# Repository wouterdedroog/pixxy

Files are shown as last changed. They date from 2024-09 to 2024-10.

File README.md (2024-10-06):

# Pixxy

Pixxy is a physical remote control for PixMob bracelets using a custom PCB. The PCB design is available in the 
[pixxy-kicad](pixxy-kicad) folder. I used KiCad 8 to design this PCB. There are currently two variations/revisions of 
this project. You're currently looking at the revision based on the RP2040 chip. 

There is also a revision based on the Raspberry Pi Pico, which is slightly cheaper and easier to assemble, but uses
micro USB instead of USB-C. This revision can be found [here](https://github.com//wouterdedroog/pixxy/tree/pico). The
MicroPython sourcecode found in the [src branch](https://github.com/wouterdedroog/pixxy/tree/src) is compatible with
both hardware versions.

## Branches
- [main](https://github.com/wouterdedroog/pixxy/tree/main) - Full project details and PCB design based on the RP2040 chip (has USB-C)
- [pico](https://github.com//wouterdedroog/pixxy/tree/pico) - PCB design based on the Raspberry Pi Pico (cheaper and easier to assemble)
- [src](https://github.com/wouterdedroog/pixxy/tree/src) - MicroPython source, compatible with both variations of Pixxy device

## Functionality
Both revisions are identical when it comes to the controls (switches and potentiometers) They both have a 4×4 button 
matrix. Eight of these buttons are used for selecting preset colours. The ninth button selects a custom colour, using 
the red/green/blue values from the potentiometers above the buttons (marked RV1, RV2 and RV3).

The Fade and Flash buttons are used to send the selected colour to the IR LED (connected to a 2N3904 transistor). The
Once / Repeat switch can be used to send the command once or multiple times.

For X2 bracelets (the ones being used at Taylor Swift concerts), it is possible to set a colour indefinitely. The On and
Off buttons are used for this. The Taylor End button sends the end/go home signal used at concerts, which causes the
bracelet to loop through a set of colours until the battery runs out. The rainbow effect does the same effect, but with
the colours of the rainbow in order.

When the Speed Set button is held down, the value of the RV3/Blue potentiometer influences the speed of the commands. 
This means the potentiometer influences how long a fade or flash command lasts, and how much time is in between these
commands if the switch is in the repeat position.

Pixxy also responds to commands over serial. You can use [this site](https://wissenhinterdenkulissen.de/armband/) which
uses WebSerial, or the Python sender scripts in the 
[pixmob-ir-reverse-engineering repo](https://github.com/danielweidman/pixmob-ir-reverse-engineering/).

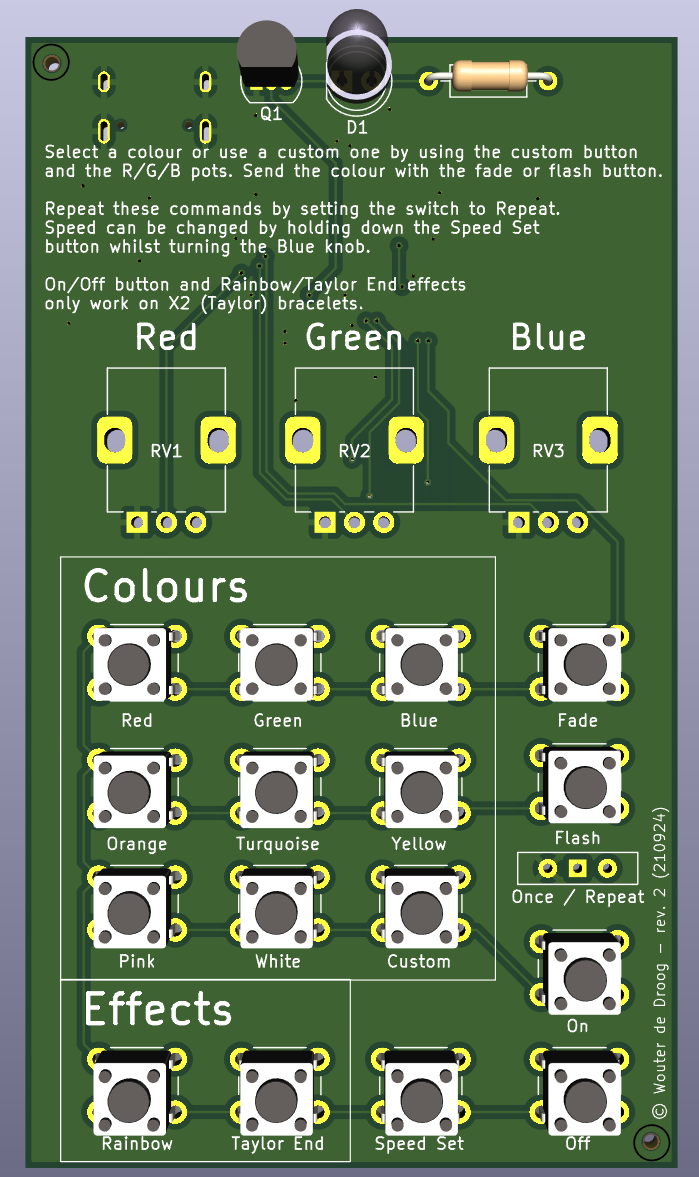
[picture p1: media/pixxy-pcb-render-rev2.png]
RP2040-based revision of the PCB


## Schematic
The PCB and schematic were made using KiCad 8. The project files are available in the
[pixxy-kicad directory](pixxy-kicad). A screenshot of the schematic can be found below:

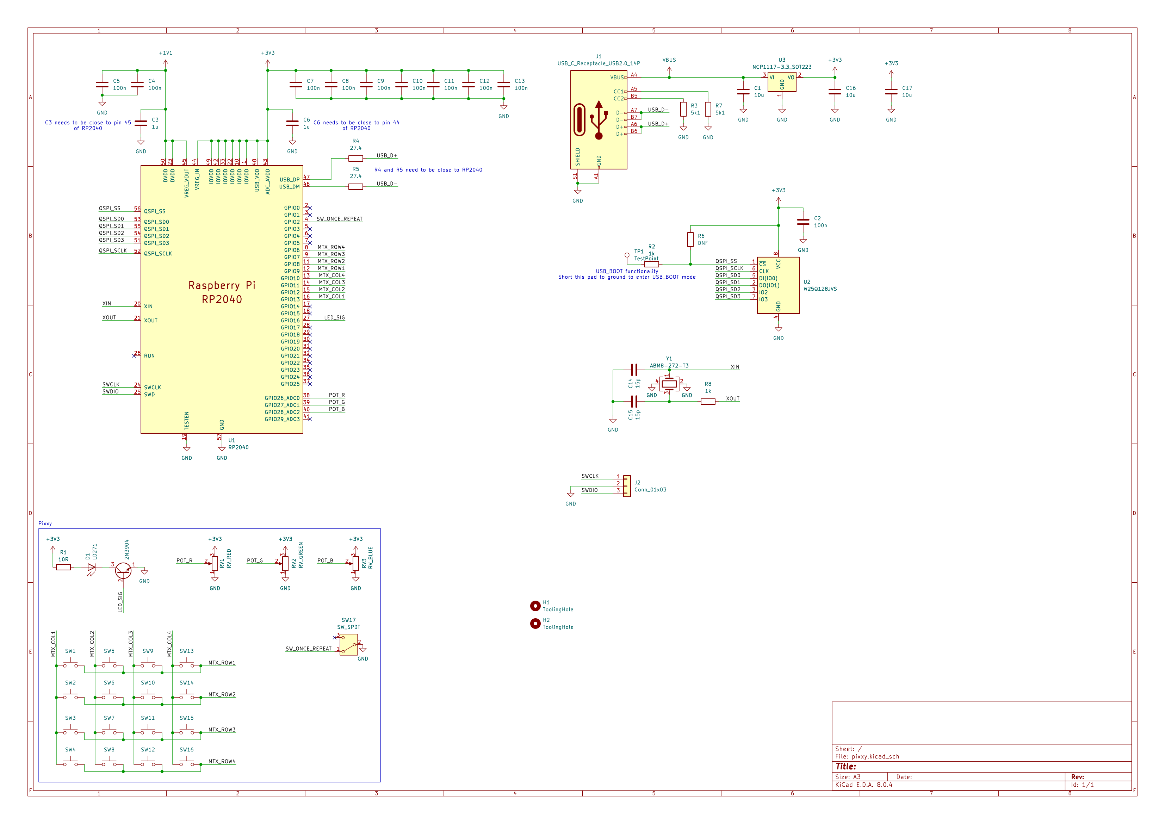
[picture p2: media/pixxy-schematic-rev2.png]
Schematic of Pixxy PCB


## Thanks
This project wouldn't have been possible without the research available in the
[pixmob-ir-reverse-engineering](https://github.com/danielweidman/pixmob-ir-reverse-engineering/) and 
[PixMob_IR](https://github.com/jamesw343/PixMob_IR/) repositories. The knowledge available in the
[PIXMOD Discord](https://discord.com/invite/UYqTjC7xp3) has also been super helpful.

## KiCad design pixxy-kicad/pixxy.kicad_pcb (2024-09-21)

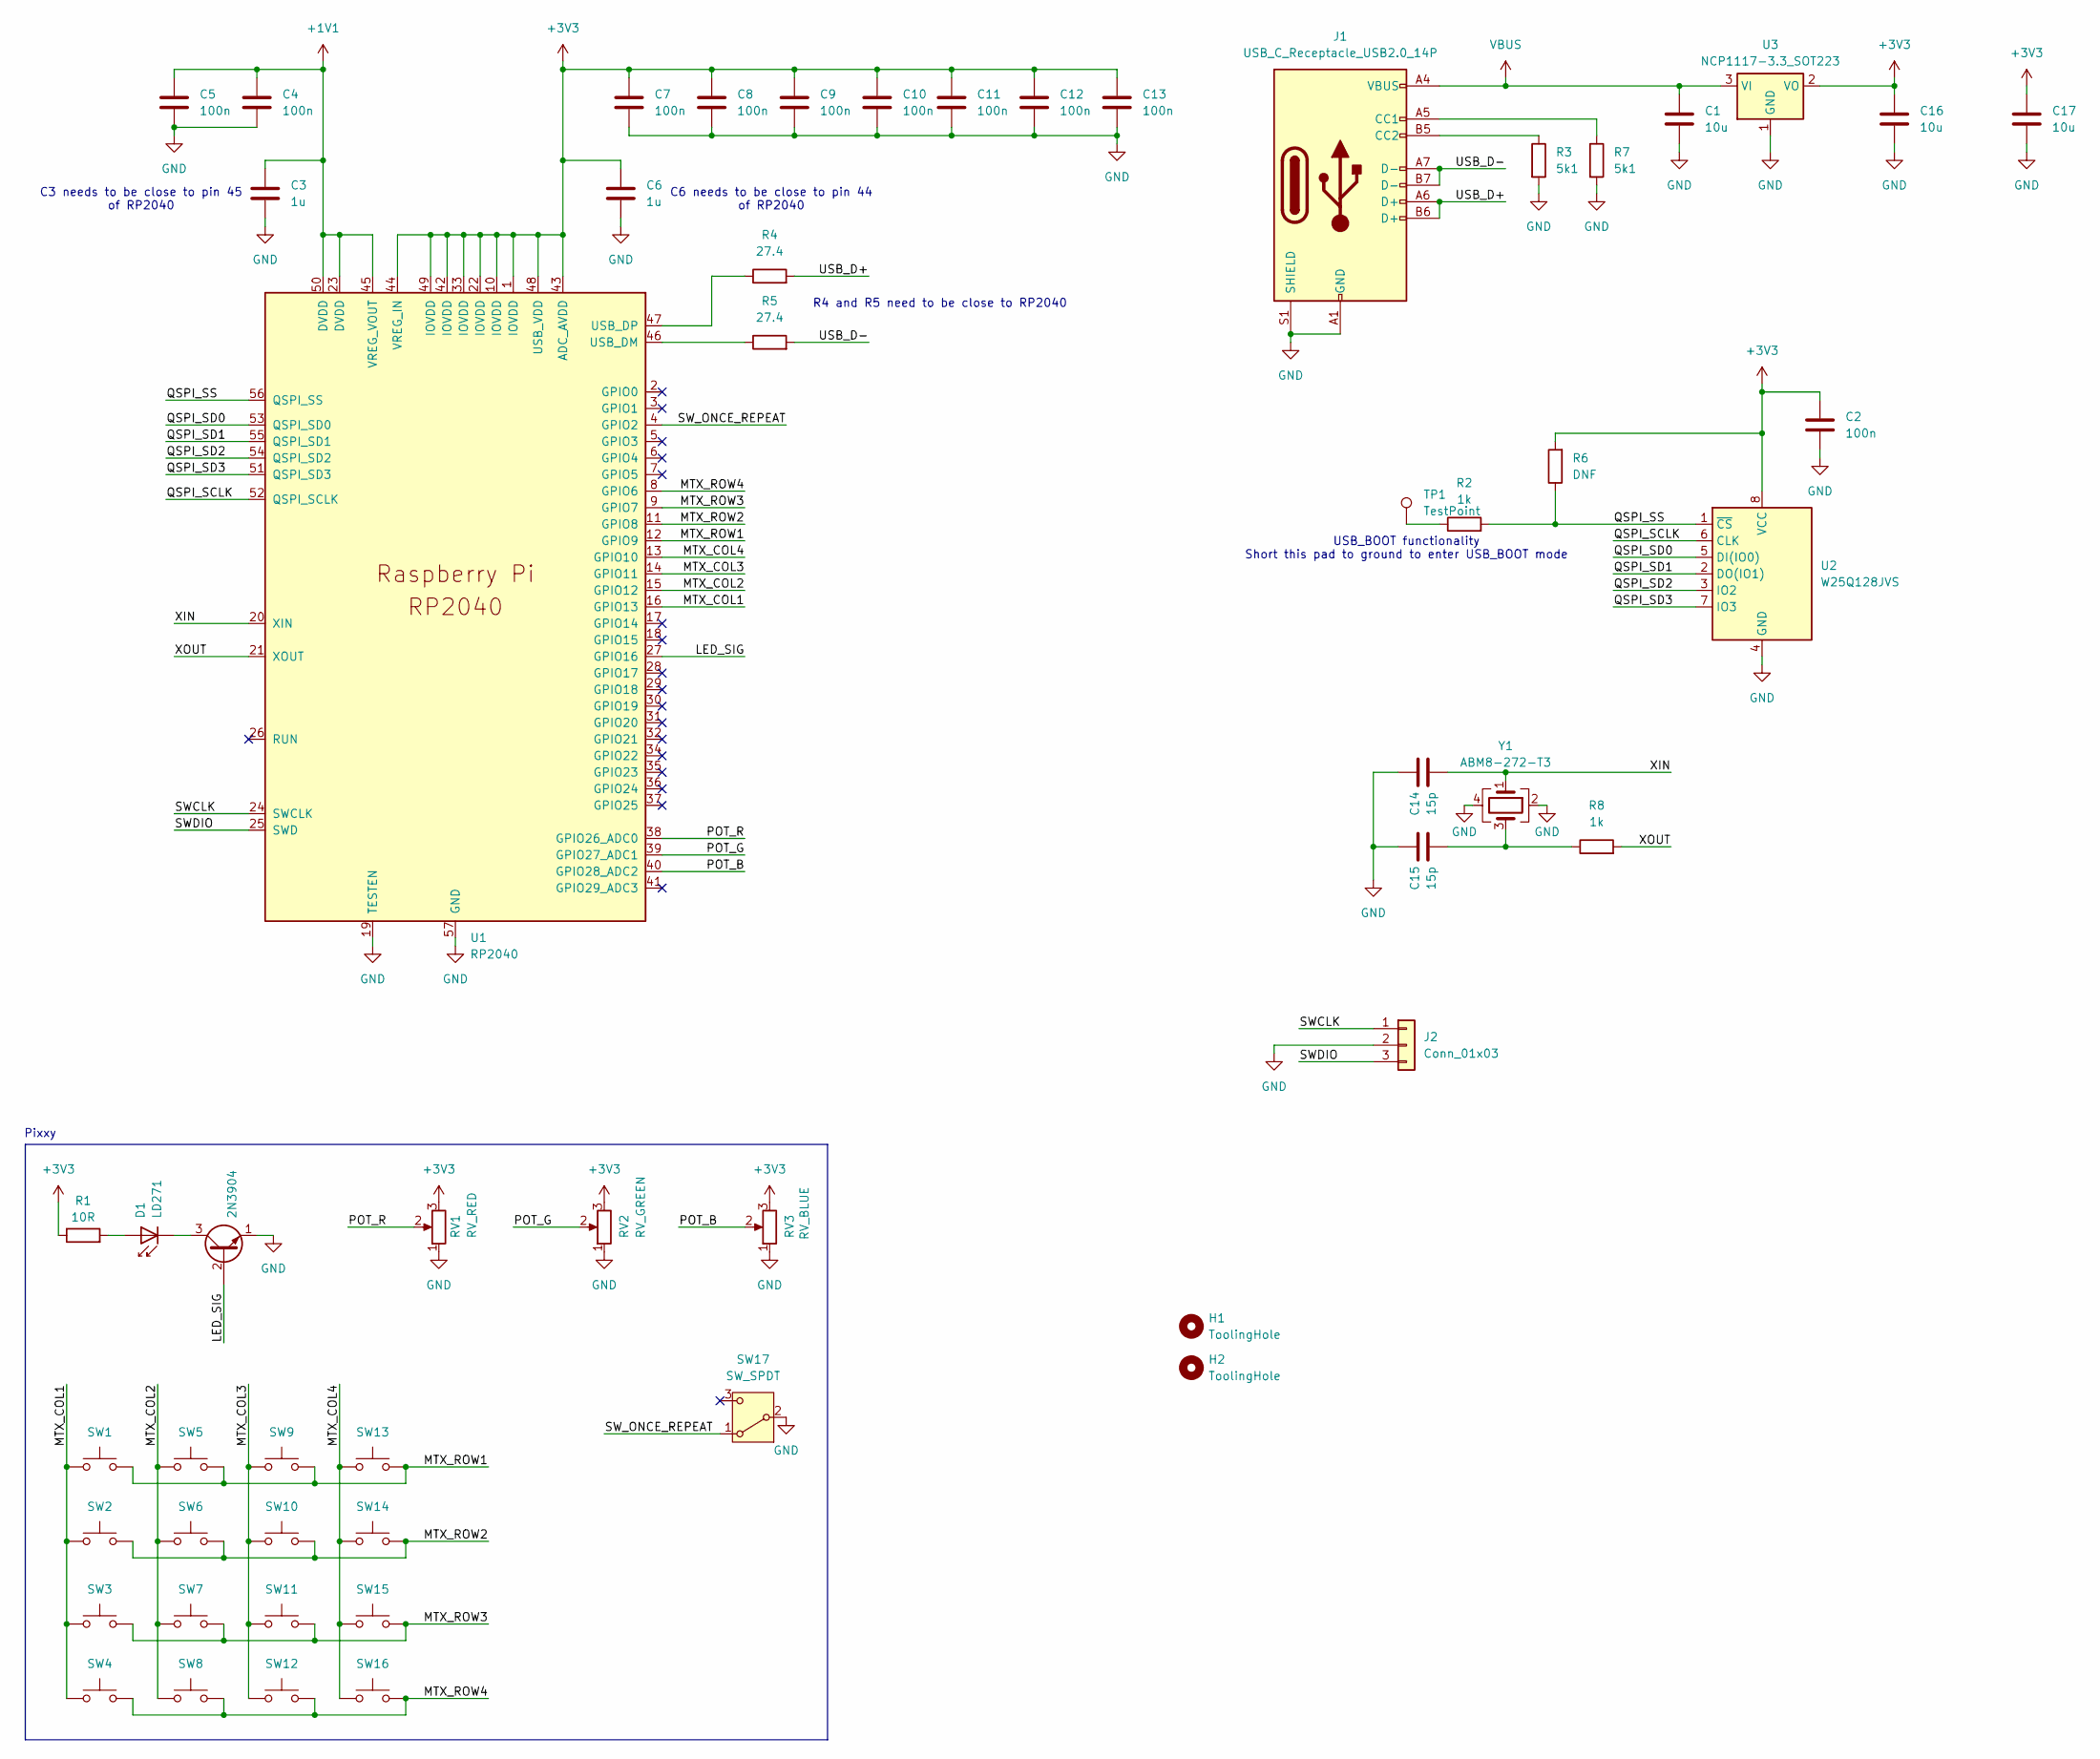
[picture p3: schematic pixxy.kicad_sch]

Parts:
C1, C16, C17: 10u; C_0805_2012Metric; LCSC C15850
C2, C4, C5, C7, C8, C9, C10, C11, C12, C13: 100n; C_0402_1005Metric; LCSC C307331
C3, C6: 1u; C_0402_1005Metric; LCSC C52923
C14, C15: 15p; C_0402_1005Metric; LCSC C1548
D1: LD271; LED_D5.0mm_IRGrey
H1, H2: ToolingHole; MountingHole_1.152mm
J1: USB_C_Receptacle_USB2.0_14P; USB_C_Receptacle_G-Switch_GT-USB-7010ASV; LCSC C2988369
J2: Conn_01x03; JST_SH_SM03B-SRSS-TB_1x03-1MP_P1.00mm_Horizontal
Q1: 2N3904; TO-92_Inline
R1: 10R; R_Axial_DIN0207_L6.3mm_D2.5mm_P10.16mm_Horizontal
R2, R8: 1k; R_0402_1005Metric; LCSC C11702
R3, R7: 5k1; R_0402_1005Metric; LCSC C25905
R4, R5: 27.4; R_0402_1005Metric; LCSC C321420
R6: DNF; R_0402_1005Metric
RV1: RV_RED; Potentiometer_Alps_RK09K_Single_Vertical
RV2: RV_GREEN; Potentiometer_Alps_RK09K_Single_Vertical
RV3: RV_BLUE; Potentiometer_Alps_RK09K_Single_Vertical
SW1, SW2, SW3, SW4, SW5, SW6, SW7, SW8, SW9, SW10, SW11, SW12, SW13, SW14, SW15, SW16: SW_PUSH_6mm
SW17: SW_SPDT; SW_Slide-03_Wuerth-WS-SLTV_10x2.5x6.4_P2.54mm
TP1: TestPoint; TestPoint_Pad_1.5x1.5mm
U1: RP2040; QFN-56-1EP_7x7mm_P0.4mm_EP3.2x3.2mm; LCSC C2040
U2: W25Q128JVS; SOIC-8_5.23x5.23mm_P1.27mm; LCSC C97521
U3: NCP1117-3.3_SOT223; SOT-223-3_TabPin2; LCSC C26537
Y1: ABM8-272-T3; Crystal_SMD_3225-4Pin_3.2x2.5mm; LCSC C20625731

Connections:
+1V1: C3.1, C4.1, C5.1, U1.23 (DVDD), U1.45 (VREG_VOUT), U1.50 (DVDD)
+3V3: C2.1, C6.1, C7.1, C8.1, C9.1, C10.1, C11.1, C12.1, C13.1, C16.1, C17.1, R1.1, R6.2, RV1.3, RV2.3, RV3.3, U1.1 (IOVDD), U1.10 (IOVDD), U1.22 (IOVDD), U1.33 (IOVDD), U1.42 (IOVDD), U1.43 (ADC_AVDD), U1.44 (VREG_IN), U1.48 (USB_VDD), U1.49 (IOVDD), U2.8 (VCC), U3.2 (VO)
/LED_SIG: Q1.2 (B), U1.27 (GPIO16)
/MTX_COL1: SW1.1, SW2.1, SW3.1, SW4.1, U1.16 (GPIO13)
/MTX_COL2: SW5.1, SW6.1, SW7.1, SW8.1, U1.15 (GPIO12)
/MTX_COL3: SW9.1, SW10.1, SW11.1, SW12.1, U1.14 (GPIO11)
/MTX_COL4: SW13.1, SW14.1, SW15.1, SW16.1, U1.13 (GPIO10)
/MTX_ROW1: SW1.2, SW5.2, SW9.2, SW13.2, U1.12 (GPIO9)
/MTX_ROW2: SW2.2, SW6.2, SW10.2, SW14.2, U1.11 (GPIO8)
/MTX_ROW3: SW3.2, SW7.2, SW11.2, SW15.2, U1.9 (GPIO7)
/MTX_ROW4: SW4.2, SW8.2, SW12.2, SW16.2, U1.8 (GPIO6)
/POT_B: RV3.2, U1.40 (GPIO28_ADC2)
/POT_G: RV2.2, U1.39 (GPIO27_ADC1)
/POT_R: RV1.2, U1.38 (GPIO26_ADC0)
/QSPI_SCLK: U1.52 (QSPI_SCLK), U2.6 (CLK)
/QSPI_SD0: U1.53 (QSPI_SD0), U2.5 (DI(IO0))
/QSPI_SD1: U1.55 (QSPI_SD1), U2.2 (DO(IO1))
/QSPI_SD2: U1.54 (QSPI_SD2), U2.3 (IO2)
/QSPI_SD3: U1.51 (QSPI_SD3), U2.7 (IO3)
/QSPI_SS: R2.2, R6.1, U1.56 (QSPI_SS), U2.1 (~CS)
/SWCLK: J2.1, U1.24 (SWCLK)
/SWDIO: J2.3, U1.25 (SWD)
/SW_ONCE_REPEAT: SW17.1 (A), U1.4 (GPIO2)
/USB_D+: J1.A6 (D+), J1.B6 (D+), R4.2
/USB_D-: J1.A7 (D-), J1.B7 (D-), R5.2
/XIN: C14.2, U1.20 (XIN), Y1.1
/XOUT: R8.2, U1.21 (XOUT)
GND: C1.2, C2.2, C3.2, C4.2, C5.2, C6.2, C7.2, C8.2, C9.2, C10.2, C11.2, C12.2, C13.2, C14.1, C15.1, C16.2, C17.2, J1.A1 (GND), J1.A12 (GND), J1.B1 (GND), J1.B12 (GND), J1.S1 (SHIELD), J2.2, Q1.1 (E), R3.2, R7.2, RV1.1, RV2.1, RV3.1, SW17.2 (B), U1.19 (TESTEN), U1.57 (GND), U2.4 (GND), U3.1 (GND), Y1.2, Y1.4
unnamed: C15.2, R8.1, Y1.3
unnamed: D1.2 (A), R1.2
unnamed: D1.1 (K), Q1.3 (C)
unnamed: J1.A5 (CC1), R7.1
unnamed: J1.B5 (CC2), R3.1
unnamed: R2.1, TP1.1
unnamed: R5.1, U1.46 (USB_DM)
unnamed: R4.1, U1.47 (USB_DP)
VBUS: C1.1, J1.A4 (VBUS), J1.A9 (VBUS), J1.B4 (VBUS), J1.B9 (VBUS), U3.3 (VI)

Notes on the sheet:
C6 needs to be close to pin 44 of RP2040
C3 needs to be close to pin 45 of RP2040
Pixxy
USB_BOOT functionality Short this pad to ground to enter USB_BOOT mode
R4 and R5 need to be close to RP2040

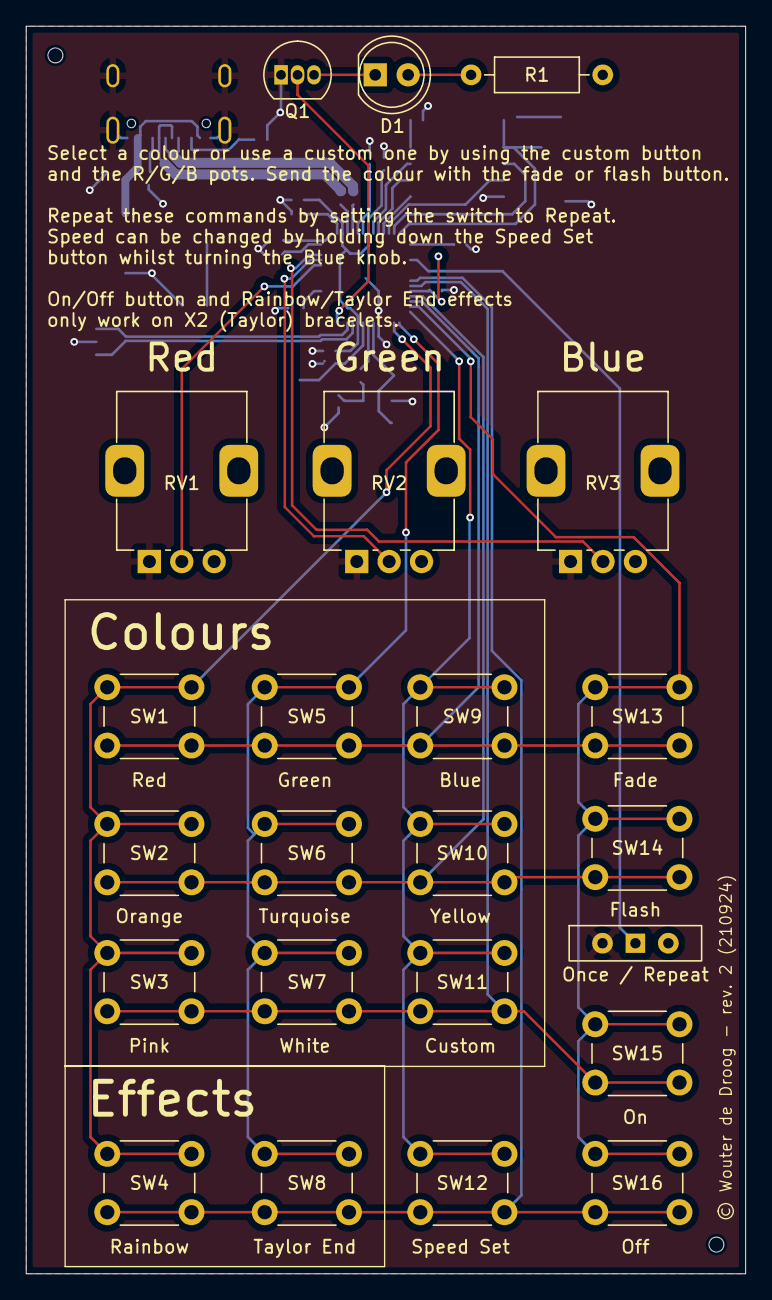
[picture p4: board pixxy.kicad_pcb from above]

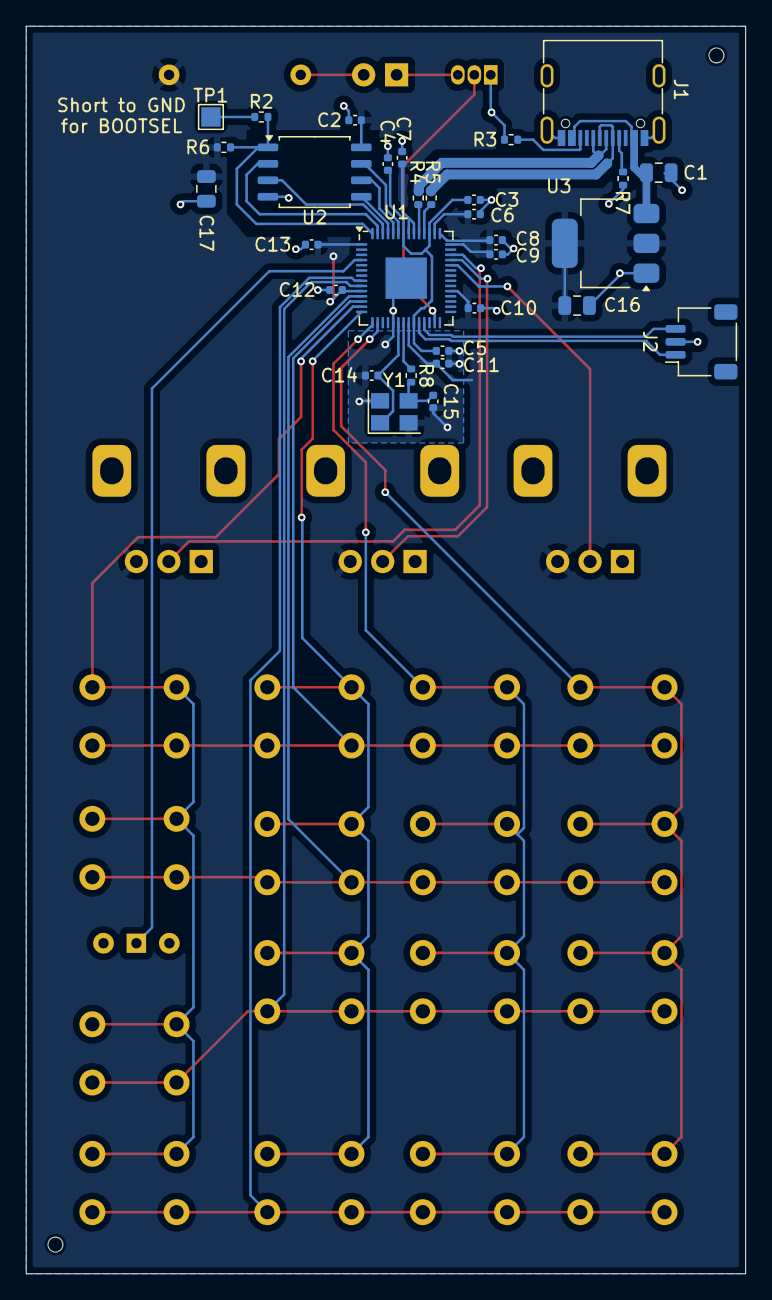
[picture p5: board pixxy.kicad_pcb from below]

Board: 2 copper layers, 55.5 x 96.2 mm, 56 parts (31 on the bottom side), 37 nets.

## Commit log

2024-08-21 Add README and initial revision of PCB
    [pixxy-B_Cu.gbl, pixxy-B_Mask.gbs, pixxy-B_Paste.gbp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]
2024-08-21 Add current Python code
    Current code does not yet support the Once / Repeat switch and Speed Set button
2024-08-30 Add initial working software, improve PCB design
    [pixxy.kicad_pcb]
2024-09-05 Fix repeat effect stopping if button on row 1 is used
2024-09-07 Add rev1 pcb files
    [pixxy.kicad_pcb, pixxy.kicad_sch]
2024-09-16 Add RP2040-based schematic
    [pixxy.kicad_sch]
2024-09-21 Improved schematic and finished pcb for rev2
    [pixxy.kicad_pcb, pixxy.kicad_sch]

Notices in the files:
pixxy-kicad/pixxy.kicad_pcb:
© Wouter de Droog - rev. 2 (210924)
